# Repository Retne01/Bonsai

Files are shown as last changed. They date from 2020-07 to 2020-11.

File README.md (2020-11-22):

# Bonsai
This is a completely through hole 75% take on the TGR Alice layout.

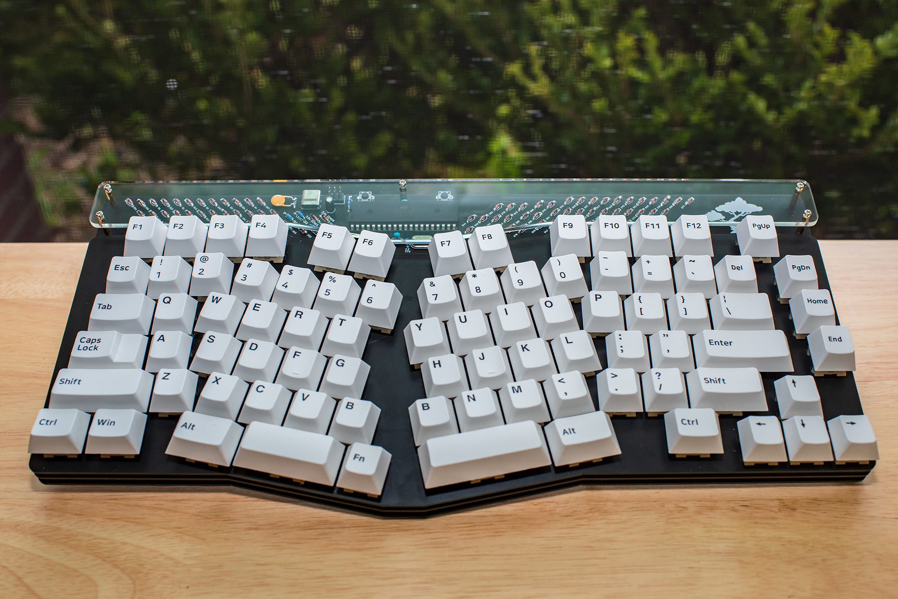
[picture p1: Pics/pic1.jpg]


If you want to put one together for yourself you can follow the guide for the FR4 sandwich style pictured above you can follow [the guide here](./Guides/FR4/)  If you would prefer to make an acrylic style case as pictured below you can follow [the guide here](./Guides/Acrylic/).

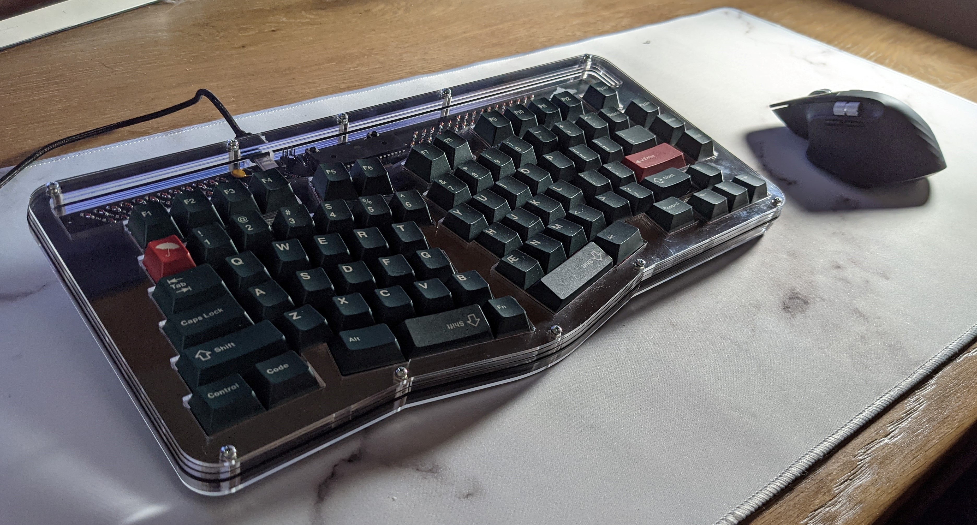
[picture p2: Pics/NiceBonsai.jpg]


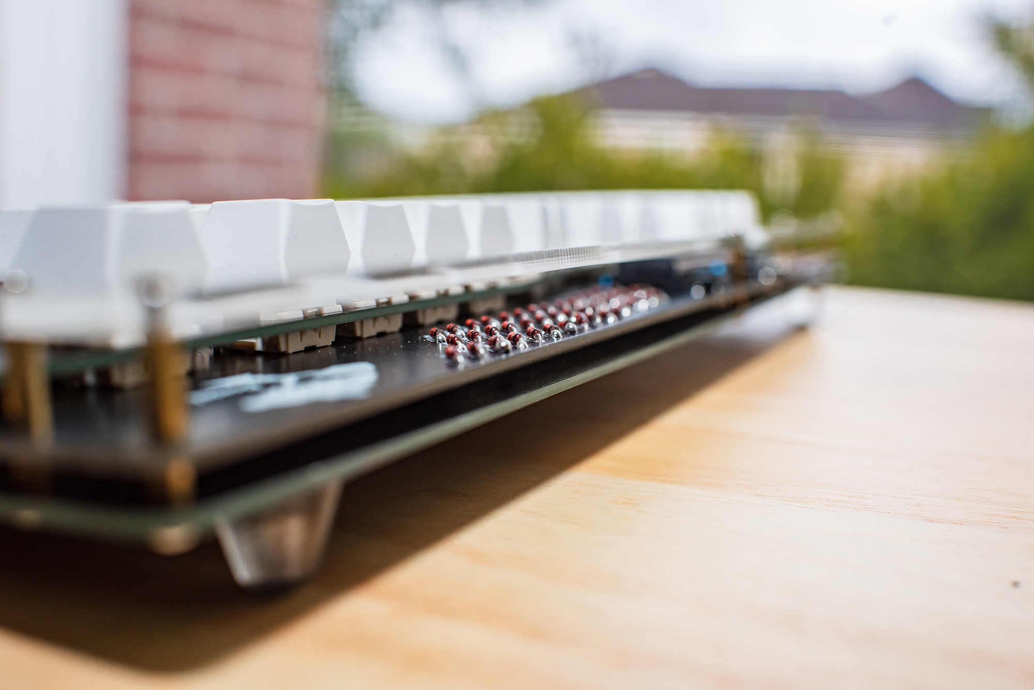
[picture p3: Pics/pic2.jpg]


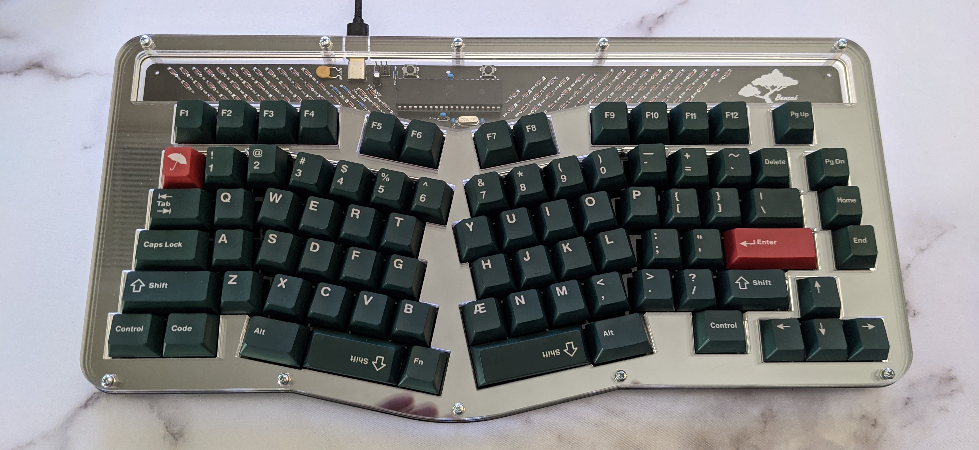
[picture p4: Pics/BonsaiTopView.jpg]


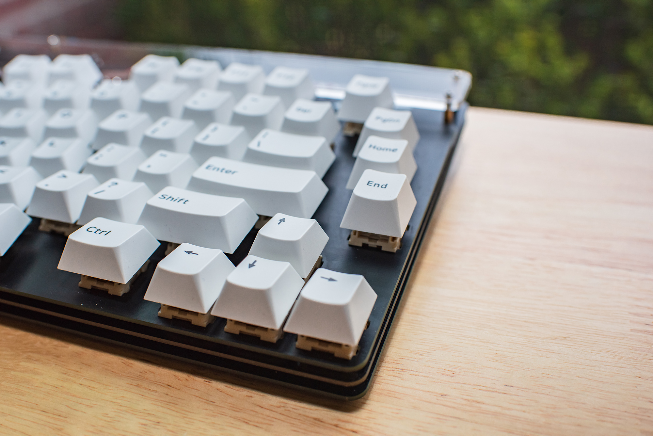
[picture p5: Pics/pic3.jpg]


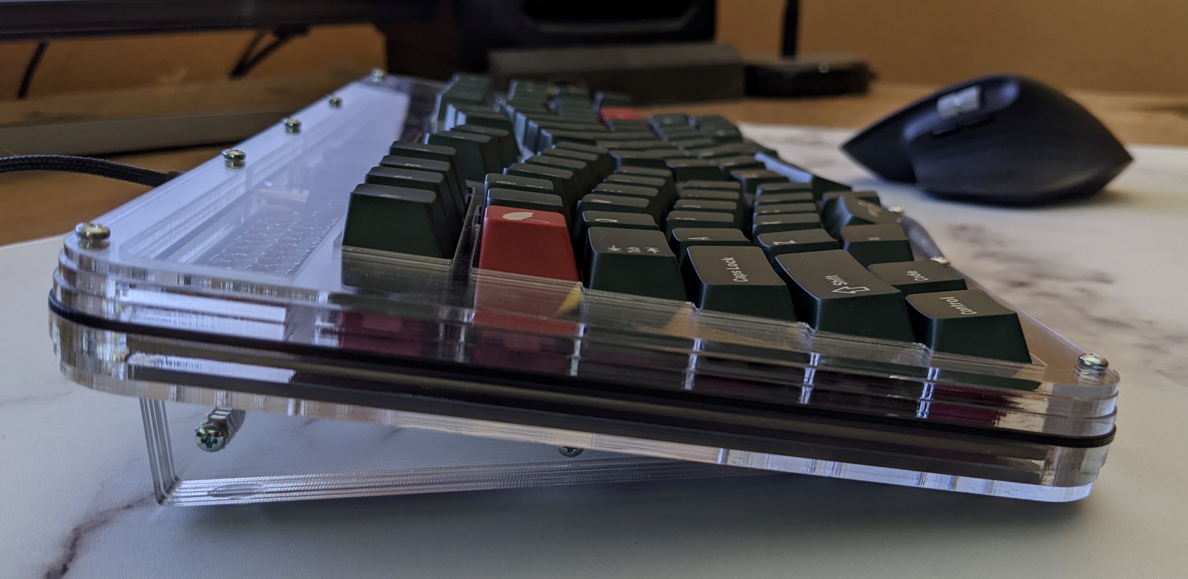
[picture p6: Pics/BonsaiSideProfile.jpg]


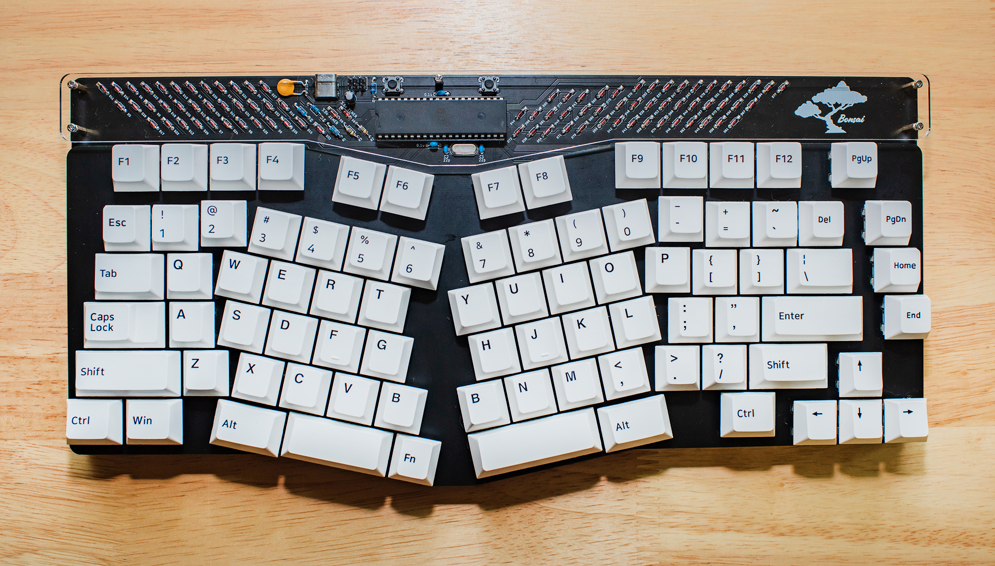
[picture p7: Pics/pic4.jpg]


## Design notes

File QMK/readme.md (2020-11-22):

# Bonsai

Bonsai

A 75% take on the Alice that can be assembled with only through hole components, including usb type-c

* Keyboard Maintainer: [Retne](https://github.com/Retne01)
* Hardware Supported: Bonsai, atmega32a
* Hardware Availability: [GitHub](https://github.com/Retne01/Bonsai)

Make example for this keyboard (after setting up your build environment):

    make bonsai:default

See the [build environment setup](https://docs.qmk.fm/#/getting_started_build_tools) and the [make instructions](https://docs.qmk.fm/#/getting_started_make_guide) for more information. Brand new to QMK? Start with our [Complete Newbs Guide](https://docs.qmk.fm/#/newbs).

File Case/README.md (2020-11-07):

# Acrylic Case for the Bonsai



This is a layered acrylic case design for the Bonsai.  The USB cutout might be a little slim so if your custom USB cable uses more than heatshrink to wrap the USB C end it probably won't fit.



If you plan to build the Bonsai with this case make sure to only order the main pcb and not the base plate or switch plate as this case will negate the need for both.



If you order this from Ponoko here are the material types and thicknesses to use:

01 - Bonsai-Top1-2mm - As the file name suggests use 2mm acrylic.

02 - Bonsai-Top2-3mm - 3mm acrylic

03 - Bonsai-Top3-3mm - 3mm acrylic

04 - Bonsai-Plate-1-5mm - 1.5mm Delrin.  This can be black or white.

05 - Bonsai-BottomOpen-4-5mm - 4.5mm acrylic

06 - Bonsai-BottomClosedwFeet-3mm - 3mm acrylic

07 - Bonsai-Bottom03mm - 3mm acrylic

You will also need [10 M2.5 14mm standoffs](https://www.harwin.com/products/R25-1001402/), [4 M2.5 11mm standoffs](https://www.harwin.com/products/R25-1001102/), [4 M2 4mm nuts](https://www.harwin.com/products/M80-2430000B/), [4 M2 6mm screws](https://www.amazon.com/gp/product/B07HGNNCLV/), and [14 M2.5 5mm screws](https://www.amazon.com/Machine-Plated-Phillips-M2-5-0-45-Threads/dp/B000NHVPPO/).

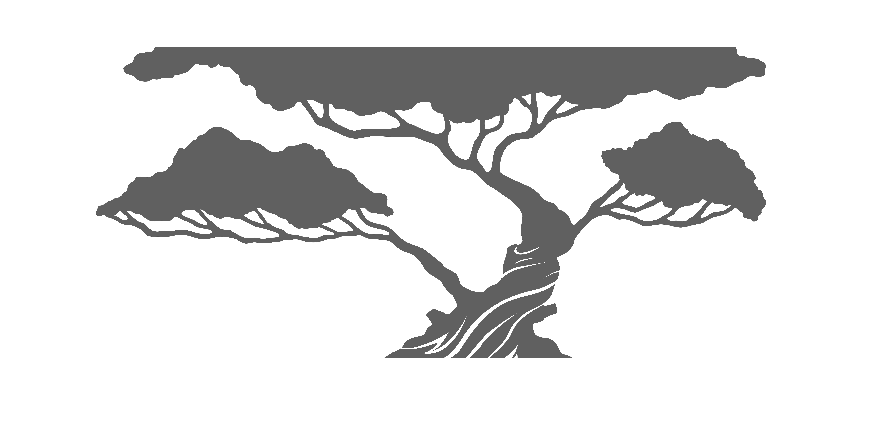
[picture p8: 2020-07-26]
Art/bonsai pcb back-01-01.png

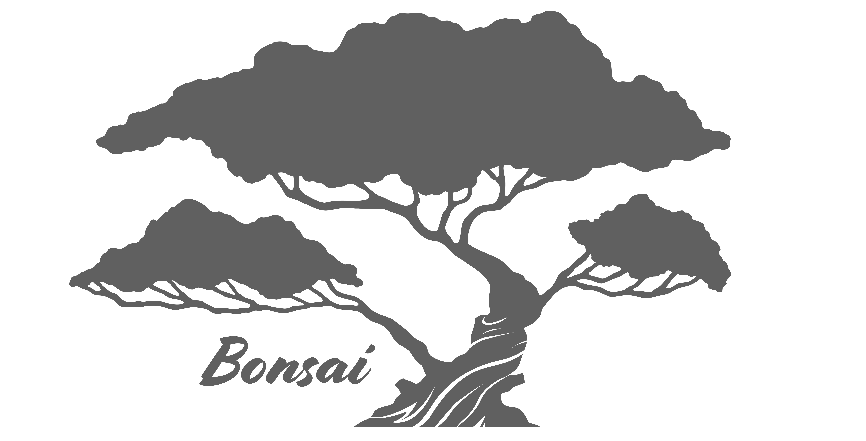
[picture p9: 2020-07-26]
Art/bonsai keyboard backplate-01-01.png

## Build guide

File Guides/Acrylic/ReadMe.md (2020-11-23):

# Acrylic Bonsai

This is a guide from start to finish of how to build an FR4 sandwich Bonsai keyboard.



1. Go to https://jlcpcb.com/ and order ONLY the "PCB Gerbers.zip" from the [Gerbers folder](https://github.com/Retne01/Bonsai/tree/master/Gerbers).  The MOQ for JLC prototypes is 5 so you will end up with 5 PCBs.

2. Order all the parts you need from the [bill of materials](https://octopart.com/bom-tool/dQECSo9X).  What vendor you choose will be up to you.  I used [Mouser](https://www.mouser.com/) and if you choose to go with them I recommend stating that you would like the parts to ship separately.  When I ordered from them I did not select this and I watched items cycle in and out of stock without them setting anything aside for my order which was very frustrating.  Another place that might be worth looking at is [LCSC](https://lcsc.com/).  I recommend trying to find a place with the majority of the items in stock if not all of them in stock as the parts are pretty darn cheap and the cost will increase exponentially if you're having to pay for shipping from multiple vendors.  I also recommend checking with your local electronic parts stores as it's always good to support local businesses.  Even if they don't stock these parts regularly they might be able to special order them for you and save you a bunch of hassle.

3. Order the acrylic case, standoffs, and screws that you will need to assemble the case.  [The files for the case can be found here](https://github.com/Retne01/Bonsai/tree/master/Case).  Pay attention to the recommended thicknesses for ordering the acrylic case from [Ponoko](https://www.ponoko.com/).  You will only need to order one of each file unless you plan to make multiple boards.  The more you order the bigger the discount.  When I ordered one case I chose to take the long wait for free shipping and the price came to roughly $127 and took roughly a month and a half to arrive.  You can also find at the bottom of that ReadMe the amount, types, and sizes of standoffs and screws.  The links to the standoffs should take you to the Harwin site and if you scroll down you can find some suggested vendors depending on where you're ordering from.  I used Mouser as the supplier of my standoffs and Amazon for the scews.  Be sure to order the [Harwin 4mm nuts](https://www.harwin.com/products/M80-2430000B/) otherwise you'll have to edit the acrylic feet to fit your chosen nut.  You'll also want to order some [bumpons](https://www.amazon.com/gp/product/B06XCGM8JT/) to go on the bottom of the feet.

4. Make sure that you have a soldering iron, some steel mesh to clean your soldering iron, some flux, some solder, and a solder sucker.  I also recommend soldering in a well ventilated area and try to have a fan pulling the solder away from the solder site as inhaling solder fumes on the regular is not good for your health.

5. Once all the parts arrive get everything together and make sure you have the correct number of parts for your build.  You should have 1x ATmega32A, 2x 75ohm resistors, 1x 1.5k resistor, 2x 5.1k resistors, 1x 10k resistor, 1x 4.7uF capacitor, 2x 0.1uF capacitors, 2x 22pF capacitors, 2x 4-pin switches, 1x 6-pin connection header, 2x 3.6v zener diodes, 1x 40-pin IC socket, 82x 1N4148 diodes, 1x 0.5amp fuse, 1x 16MHz crystal, and 1x USB-C port.

6. Solder 82x 1N4148 Diodes.  These have a specific orientation.  The black bar will be oriented upwards and go on the side with the square pad.

7. Solder the 2x 3.6v zener diodes.  These have a specific orientation.  The black bar will be oriented upwards and go on the side with the square pad.

8. Solder the 2x 75ohm, 1.5k, 2x 5.1k, and 10k resistors.  These do not hace a specific orientation.

9. Solder the USB-C port.  This will be the most dificult part and I recommend having flux on hand.  Insert the port and then solder one of the large legs to secure the port to the board.  Then heat the one leg you soldered up and press the port into the board to make sure it is flush with the board.  Apply a large amount of flux to the soldering area.  This will help you to not bridge any of the pins.  Solder the 3 legs.  Now take your iron and apply solder to the iron itself and then drag it across the pins.  Inspect to make sure all the pins are soldered and that none of them are connected to each other with solder.  If you do have two pins connected with solder, clean your iron and then heat the area with the bridged pins and pull away some of the solder.  If when you plug the board into your computer for testing you get a USB port voltage error you will know you have bridged pins and you need to inspect them again, apply flux, and try to pull away solder until none of the pins are touching but they are all soldered.

10. Solder the 2x 4-pin switches.  These have no specific orientation.

11. Solder the 0.5amp fuse.  This has no specific orientation.

12. Solder the 6-pin header.  The longer side is the bit you want sticking out of the top of your board.  I would recommend soldering 1 pin and then reheating that 1 pin and pressing the header in to make sure it sits flush with the board.

13. Solder the 16MHz crystal.  This has no specific orientation.

14. Solder the 2x 22pF capacitors.  These have no specific orientation.

15. Solder the 2x 0.1uF capacitors.  These have no specific orientation.

16. Solder the 40-pin IC socket.  This has a specific orientation.  Do not inset the MCU before soldering the IC socket.  Align the notch on the socket with the notch printed on the board.  Solder 2 pins in opposite corners.  Then reheat one pin and push down on that side and do the same with the other until the socket is flush with the board.

17. Insert the ATmega32A into the IC socket.  Be sure to line up the notch on the MCU with the notch on the socket.  You may need to gently bend the pin legs to get them aligned with the socket.  I recommend sticking one sideof the MCU's legs into the socket and gently bending the opposite legs to align with the socket and then gently pressing the MCU into the socket.  Then solder the rest of the pins.

18. It's time to flash the bootloader.  Get your AVR programmer out and download [the bootloader](https://github.com/Retne01/Bonsai/tree/master/Bootloader).  Install [WinAVR](http://winavr.sourceforge.net/) and [set up your QMK build environment](https://beta.docs.qmk.fm/tutorial/newbs_getting_started).  If you are not using a Sparkfun Pocket AVR Programmer you will need to edit the makefile.inc to use the programmer of your choice.  Be sure to only edit the makefile.inc and not the makefile itself.  Once done connect your programmer to the 6-pin header and open MinGW64.  Navigate to the bootloader directory and run these two commands

	```make flash```
	```make fuse```

The USB bootloader should now be flashed.  You can now remove your AVR Programmer.

19. Now we'll flash your desired QMK firmware layout to the MCU.  Connect the board to your computer with a USB cable and hold down the boot switch, tap the reset switch, and release the boot switch.  You can also hold down the boot switch while inserting the USB cable into the board if you prefer.  This will put the board into bootloader mode.  Make sure you've downloaded the [bonsai QMK source](https://github.com/Retne01/Bonsai/tree/master/QMK) and put it in $/qmk_firmware/keyboards/bonsai/.  Open MinGW64 and navigate to $/qmk_firmware/.  Then run one of the following commands depending on your preferred layout:

	```make bonsai:default:flash```
	
	or

	```make bonsai:split_bksp:flash```

You should see something similar to this:

![](./pics/qmkflash.jpg)

Your keyboard should now be flashed and you can now unplug the USB cable.  I have not added this board to QMK with a pull request because I expect very few people to be interested in the board at all.  If you want to edit the layout you can look at the source I've provided and edit it to your liking.  You can find a list of [qmk key codes here](https://beta.docs.qmk.fm/using-qmk/simple-keycodes/keycodes).

20.  Plug your board back in, grab a pair of tweesers and test to make sure all of the switch holes are working in whatever keyboard tester you prefer.

21. Now grab your acrylic parts, standoffs, and screws.  You should have 6 acrylic layers and one POM/Delrin layer.  For your standoffs and screws you should have 10x M2.5 14mm standoffs, 4x M2.5 11mm standoffs, 4x M2 4mm nuts, 4x M2 6mm screws, and 14x M2.5 5mm screws.

22. Lube, assemble, and attach your stabalizers to the board.  You will need 4 or 5 depending on if you are splitting the backspace or not.

23. Line up the POM plate with the board and insert all of your switches.  If you have trouble getting them to insert fully into the plate you can insert almost all the switches into the plate and then line it up with the board to insert the last few.

24. Solder your switches into the board.  I recommend soldering one leg on a handful of switches around the board and then reflowing the joints while pressing the switches into the board to ensure you get them nice and flush with the PCB.  Once you've got everything sitting flush go ahead and solder the rest of your switch legs.

25. Now take the 12x acrylic triangles and separate them into 2 piles with 2 of each kind going into the piles.  Then take from one pile one of the triangles with the hexaganal cutouts but no notch and line it up with 2 of the triangles from the pile that have the hexaganal cutouts AND the notch.  Then align those with one of the triangles that only has screw holes from the same pile.  Slide 2x 11mm standoffs into the hexaganal holes and screw them into the triangle with screw holes.  Now slide 2x 4mm nuts into the notches, align the last triangle with hexaganal cutouts, and finally align the last triangle from the pile with screw holes and screw them into the standoffs.  Now duplicate the process with the other pile and you will have your case feet.

26. Use the 4x M2 screws to screw the feet into the base of the case (layer 7) by aligning the holes in the middle of the base with the nuts in the feet.

27. Now take layer 6 of the case and line it up with the base of the case.  Slot in all 10x M2.5 14mm standoffs and screw them into the base lightly.

28. Stack layer 5 on top of layer 6 and then slide the assembled board in.

29. Stack layer 3, 2, and 1 on top of the plate and screw the top into the standoffs.

Congratulations, you now have an Acrylic Bonsai to type away with.

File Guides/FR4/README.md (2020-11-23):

# FR4 Sandwich Bonsai

This is a guide from start to finish of how to build an FR4 sandwich Bonsai keyboard.



1. Go to https://jlcpcb.com/ and order all 3 gerbers from the [Gerbers folder](https://github.com/Retne01/Bonsai/tree/master/Gerbers).  There are 3 of them.  The base plate, the pcb, and the switch plate.  The MOQ for JLC prototypes is 5 so you will end up with 5 of each.  If they ask you about missing copper in the switch plate or base plate just tell them that you don't need copper in those but definitely make sure to go with a pcb color.  With default pcb coloring they may look worse than if you opt for something like Black.  They may also ask you about the drill holes being too close together on the switch plate.  Tell them that you will accept damages and they will make it.  I had all 5 of my FR4 switch plates come out just fine and I had to do this.

2. Order all the parts you need from the [bill of materials](https://octopart.com/bom-tool/dQECSo9X).  What vendor you choose will be up to you.  I used [Mouser](https://www.mouser.com/) and if you choose to go with them I recommend stating that you would like the parts to ship separately.  When I ordered from them I did not select this and I watched items cycle in and out of stock without them setting anything aside for my order which was very frustrating.  Another place that might be worth looking at is [LCSC](https://lcsc.com/).  I recommend trying to find a place with the majority of the items in stock if not all of them in stock as the parts are pretty darn cheap and the cost will increase exponentially if you're having to pay for shipping from multiple vendors.  I also recommend checking with your local electronic parts stores as it's always good to support local businesses.  Even if they don't stock these parts regularly they might be able to special order them for you and save you a bunch of hassle.

3. Order [some standoffs](https://www.amazon.com/gp/product/B07B9X1KY6/) and [bumpons](https://www.amazon.com/gp/product/B06XCGM8JT/) of [different heights](https://www.amazon.com/gp/product/B07KGKZFQN/).  The stuff I'm linking to here is what I ordered for my project but there may be better stuff out there.  The standoffs will determine the height of the PCB from the Base Plate and the bumpons will determine the angle of the board.  With the two bumpons I linked if the small ones are used at the front of the keyboard and the large ones at the back you will get roughly a 5-6 degree typing angle.  I haven't measured it but it lined up pretty close with my tofu65.

4. Order the acrylic window for your keyboard.  You can use the SVG [found here](https://github.com/Retne01/Bonsai/tree/master/Acrylic%20Top) to order them cut at [Ponoko](https://www.ponoko.com/) or whichever laser cutting service you prefer.  Just be sure to order clear acrylic to show off your soldering work!

5. Make sure that you have a soldering iron, some steel mesh to clean your soldering iron, some flux, some solder, and a solder sucker.  I also recommend soldering in a well ventilated area and try to have a fan pulling the solder fumes away from the solder site as inhaling solder fumes on the regular is not good for your health.

6. Once all the parts arrive get everything together and make sure you have the correct number of parts for your build.  You should have 1x ATmega32A, 2x 75ohm resistors, 1x 1.5k resistor, 2x 5.1k resistors, 1x 10k resistor, 1x 4.7uF capacitor, 2x 0.1uF capacitors, 2x 22pF capacitors, 2x 4-pin switches, 1x 6-pin connection header, 2x 3.6v zener diodes, 1x 40-pin IC socket, 82x 1N4148 diodes, 1x 0.5amp fuse, 1x 16MHz crystal, and 1x USB-C port.

7. Solder 82x 1N4148 Diodes.  These have a specific orientation.  The black bar will be oriented upwards and go on the side with the square pad.

8. Solder the 2x 3.6v zener diodes.  These have a specific orientation.  The black bar will be oriented upwards and go on the side with the square pad.

9. Solder the 2x 75ohm, 1.5k, 2x 5.1k, and 10k resistors.  These do not hace a specific orientation.

10. Solder the USB-C port.  This will be the most dificult part and I recommend having flux on hand.  Insert the port and then solder one of the large legs to secure the port to the board.  Then heat the one leg you soldered up and press the port into the board to make sure it is flush with the board.  Apply a large amount of flux to the soldering area.  This will help you to not bridge any of the pins.  Solder the 3 legs.  Now take your iron and apply solder to the iron itself and then drag it across the pins.  Inspect to make sure all the pins are soldered and that none of them are connected to each other with solder.  If you do have two pins connected with solder, clean your iron and then heat the area with the bridged pins and pull away some of the solder.  If when you plug the board into your computer for testing you get a USB port voltage error you will know you have bridged pins and you need to inspect them again, apply flux, and try to pull away solder until none of the pins are touching but they are all soldered.

11. Solder the 2x 4-pin switches.  These have no specific orientation.

12. Solder the 0.5amp fuse.  This has no specific orientation.

13. Solder the 6-pin header.  The longer side is the bit you want sticking out of the top of your board.  I would recommend soldering 1 pin and then reheating that 1 pin and pressing the header in to make sure it sits flush with the board.

14. Solder the 16MHz crystal.  This has no specific orientation.

15. Solder the 2x 22pF capacitors.  These have no specific orientation.

16. Solder the 2x 0.1uF capacitors.  These have no specific orientation.

17. Solder the 40-pin IC socket.  This has a specific orientation.  Do not inset the MCU before soldering the IC socket.  Align the notch on the socket with the notch printed on the board.  Solder 2 pins in opposite corners.  Then reheat one pin and push down on that side and do the same with the other until the socket is flush with the board.  Then solder the rest of the pins.

18. Insert the ATmega32A into the IC socket.  Be sure to line up the notch on the MCU with the notch on the socket.  You may need to gently bend the pin legs to get them aligned with the socket.  I recommend sticking one sideof the MCU's legs into the socket and gently bending the opposite legs to align with the socket and then gently pressing the MCU into the socket.

19. It's time to flash the bootloader.  Get your AVR programmer out and download [the bootloader](https://github.com/Retne01/Bonsai/tree/master/Bootloader).  Install [WinAVR](http://winavr.sourceforge.net/) and [set up your QMK build environment](https://beta.docs.qmk.fm/tutorial/newbs_getting_started).  If you are not using a Sparkfun Pocket AVR Programmer you will need to edit the makefile.inc to use the programmer of your choice.  Be sure to only edit the makefile.inc and not the makefile itself.  Once done connect your programmer to the 6-pin header and open MinGW64.  Navigate to the bootloader directory and run these two commands

	```make flash```
	```make fuse```

The USB bootloader should now be flashed.  You can now remove your AVR Programmer.

20. Now we'll flash your desired QMK firmware layout to the MCU.  I've found that QMK Toolbox does not like to work with the board until I've already flashed QMK to it so for these next steps you'll need to have the qmk build environment set up.  Connect the board to your computer with a USB cable and hold down the boot switch, tap the reset switch, and release the boot switch.  You can also hold down the boot switch while inserting the USB cable into the board if you prefer.  This will put the board into bootloader mode.  Make sure you've downloaded the [bonsai QMK source](https://github.com/Retne01/Bonsai/tree/master/QMK) and put it in $/qmk_firmware/keyboards/bonsai/.  Open MinGW64 and navigate to $/qmk_firmware/.  Then run one of the following commands depending on your preferred layout:

	```make bonsai:default:flash```

	or
	
	```make bonsai:split_bksp:flash```

You should see something similar to this:

![](./pics/qmkflash.jpg)

Your keyboard should now be flashed and you can now unplug the USB cable.  I have not added this board to QMK with a pull request because I expect very few people to be interested in the board at all.  If you want to edit the layout you can look at the source I've provided and edit it to your liking.  You can find a list of [qmk key codes here](https://beta.docs.qmk.fm/using-qmk/simple-keycodes/keycodes).

21. Plug your board back in, grab a pair of tweesers and test to make sure all of the switch holes are working in whatever keyboard tested you prefer.

22. Now you will need to gather your standoffs, screws, MX switches of your choice, the switch plate, and the base plate.

23. Choose the height of standoff you want for connected the base plate to the board and be sure to use female to female standoffs.  Screw the standoffs that connect below the switch plate into the bottom of the board.  Then screw in the 5 standoffs that go into the top of the board.  For the top of the board you will use the longer male to female standoffs and female to female standoffs of the same size as the ones you previously selected on the bottom of the board.

24. Lube, assemble, and attach your stabalizers to the board.

25. Insert the MX switches into the switch plate and into the board.

26. Solder one leg of a handful of switches across the board to act as anchor points.  Then reflow each switch and be sure to push it all the way into the board until it is flush with the board.  Then solder the rest of the switch legs.

27. Screw in the base plate to the standoffs on the back of the board and screw the acrylic window into the standoffs at the top of the board.

Congratulations, you now have an FR4 Bonsai of your very own.

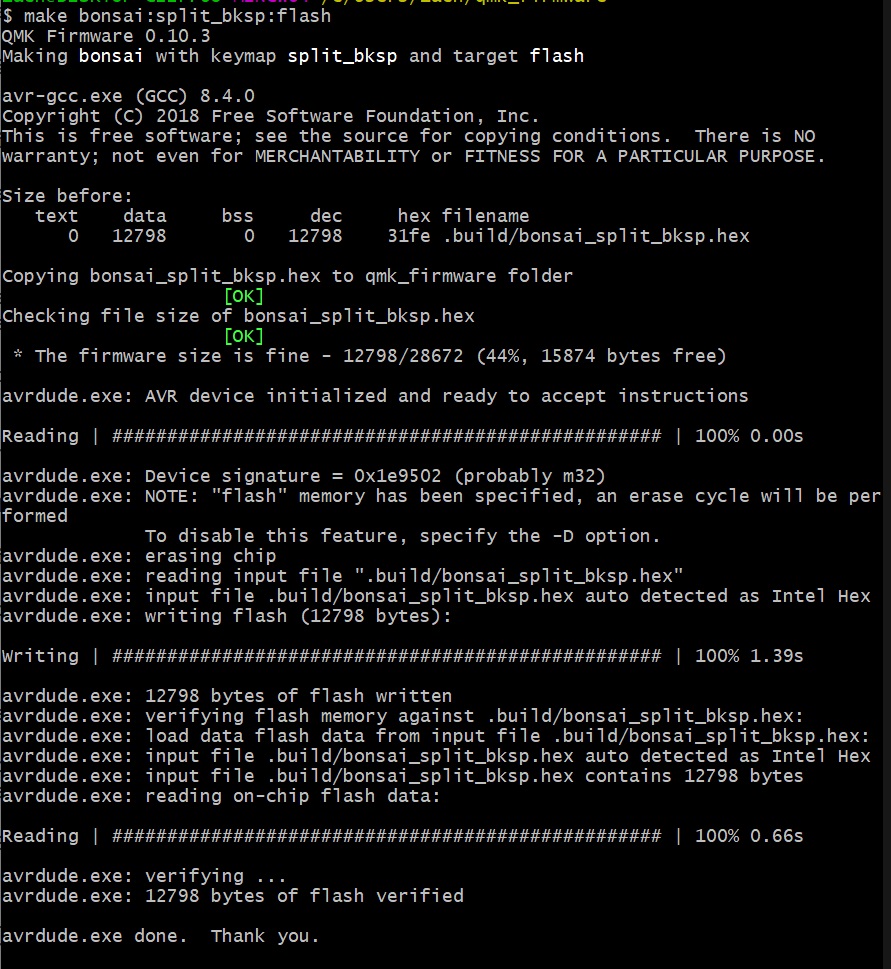
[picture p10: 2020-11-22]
Guides/FR4/pics/qmkflash.jpg

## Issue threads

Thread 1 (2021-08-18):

Gerber Files

killrmodz, 2021-08-18:
Currently, JLPCB is unable to process the main gerber files for the pcb.  Just wanted to bring this to your attention as I wanted to order some PCB's.

Thanks!

Retne01, 2021-08-18:
What do they say is the issue?  Or is it their automated system not working
with it?

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

killrmodz, 2021-08-18:
It seems like their automated system maybe when uploading gerber files with the main pcb?  The plates will upload.  Man pcb says it completes but the gerber viewer doesn’t show up.  Led me to contacting you on github.

Ismael Justiniano
Owner/Founder of killRMODZ
Facebook.com/killrmoddingz

On Aug 18, 2021, at 7:32 AM, Retne01 ***@***.***> wrote:

What do they say is the issue? Or is it their automated system not working
with it?

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

—
You are receiving this because you authored the thread.
Reply to this email directly, view it on GitHub<https://na01.safelinks.protection.outlook.com/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>, or unsubscribe<https://na01.safelinks.protection.outlook.com/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>.
Triage notifications on the go with GitHub Mobile for iOS<https://na01.safelinks.protection.outlook.com/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> or Android<https://na01.safelinks.protection.outlook.com/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>.

Retne01, 2021-08-18:
Sometimes JLC's Gerber viewer doesn't work properly but they can still make
the pcb just fine. I'll take a look tonight and see if I have the same
issue and get back to you.

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

killrmodz, 2021-08-18:
You rock, thanks!

Ismael Justiniano
Owner/Founder of killRMODZ
Facebook.com/killrmoddingz

On Aug 18, 2021, at 7:41 AM, Retne01 ***@***.***> wrote:

Sometimes JLC's Gerber viewer doesn't work properly but they can still make
the pcb just fine. I'll take a look tonight and see if I have the same
issue and get back to you.

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

—
You are receiving this because you authored the thread.
Reply to this email directly, view it on GitHub<https://na01.safelinks.protection.outlook.com/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>, or unsubscribe<https://na01.safelinks.protection.outlook.com/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>.
Triage notifications on the go with GitHub Mobile for iOS<https://na01.safelinks.protection.outlook.com/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> or Android<https://na01.safelinks.protection.outlook.com/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>.

Retne01, 2021-08-18:
It does indeed appear to just be typical JLC bugginess of their gerber
preview.  You should still be able to proceed with the order.  I was able
to upload the gerbers fine but you will have to manually enter the pcb size
which is 349mm x 166mm.  Once you purchase it the engineers at JLC will
ingest the gerbers.  They will most likely ask you "Will you accept broken
PCBs?" on the plate gerbers since the drill points are closer than their
safety spec.  Don't worry though they will still come out fine.  Mine came
out clean and CFT has used JLC for FR4 plates with similar
positive results.  They'll also likely ask if the base or the plate needs a
ground pour or not.  It does not and it should make the parts cheaper to
get them without.

If the engineers get back to you and tell you there is an issue with the
PCB gerber let me know and I'll regenerate the gerbers and replace them on
github.  Feel free to hit me up if you have any questions when building and
flashing and I'll do my best to help.

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

killrmodz, 2021-08-19:
You’re awesome!!  Im a professional modder that makes custom water cooled pc.  Ever need any custom work, just hit me up!

Ill let you know how it goes!

Ismael Justiniano
Owner/Founder of killRMODZ
Facebook.com/killrmoddingz

On Aug 18, 2021, at 7:50 PM, Retne01 ***@***.***> wrote:

It does indeed appear to just be typical JLC bugginess of their gerber
preview. You should still be able to proceed with the order. I was able
to upload the gerbers fine but you will have to manually enter the pcb size
which is 349mm x 166mm. Once you purchase it the engineers at JLC will
ingest the gerbers. They will most likely ask you "Will you accept broken
PCBs?" on the plate gerbers since the drill points are closer than their
safety spec. Don't worry though they will still come out fine. Mine came
out clean and CFT has used JLC for FR4 plates with similar
positive results. They'll also likely ask if the base or the plate needs a
ground pour or not. It does not and it should make the parts cheaper to
get them without.

If the engineers get back to you and tell you there is an issue with the
PCB gerber let me know and I'll regenerate the gerbers and replace them on
github. Feel free to hit me up if you have any questions when building and
flashing and I'll do my best to help.

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

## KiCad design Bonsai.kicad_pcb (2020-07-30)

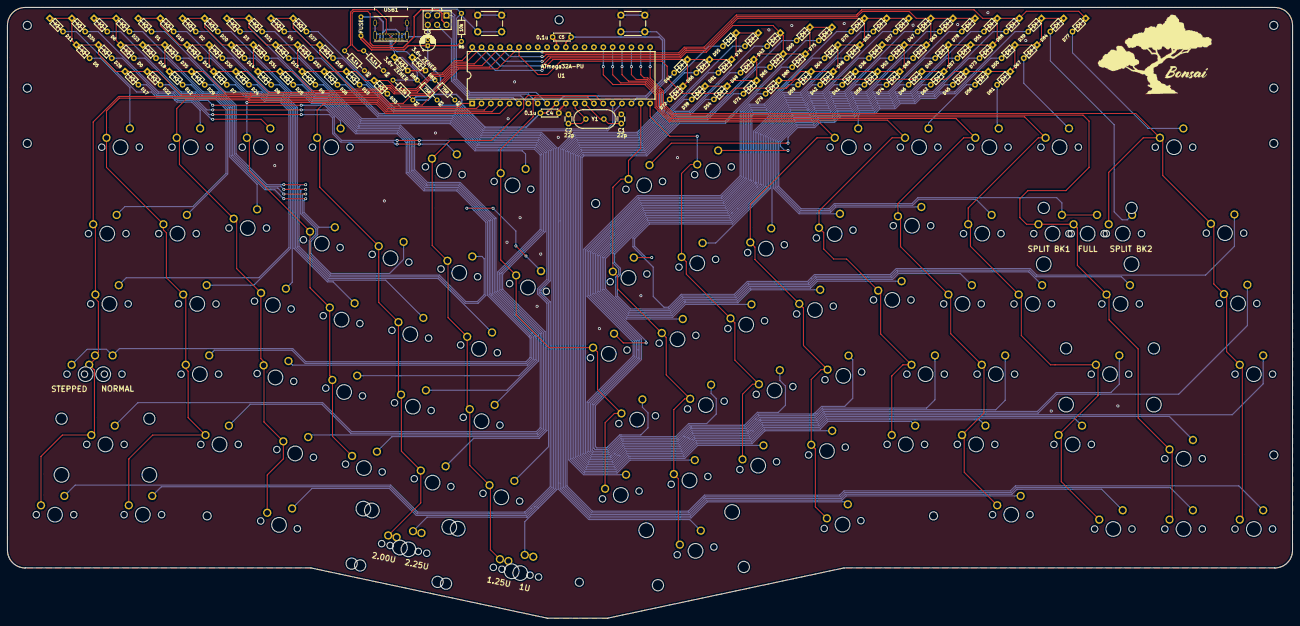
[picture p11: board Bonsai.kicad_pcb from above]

Board: 2 copper layers, 348.5 x 165.6 mm, 203 parts (0 on the bottom side), 120 nets.

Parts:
BOOT1: BOOT; SW_PUSH_6mm
C1, C2: 22p; C_Disc_D3.0mm_W1.6mm_P2.50mm
C3: 4.7u; CP_Radial_D4.0mm_P1.50mm
C4, C5: 0.1u; C_Disc_D4.3mm_W1.9mm_P5.00mm
D0, D1, D2, D3, D4, D5, D6, D7, D8, D9, D10, D11, D12, D13, D14, D15, D16, D17, D18, D19, D20, D21, D22, D23, D24, D25, D26, D27, D28, D29, D30, D31, D32, D33, D34, D35, D36, D37, D38, D39, D40, D41, D42, D43, D44, D45, D46, D47, D48, D49, D50, D51, D52, D53, D54, D55, D56, D57, D58, D59, D60, D61, D62, D63, D64, D65, D66, D67, D68, D69, D70, D71, D72, D73, D74, D75, D76, D77, D78, D79, D80, D81, D84: D; D_DO-35_SOD27_P5.08mm_Horizontal
D82, D83: 3.6v; D_DO-35_SOD27_P5.08mm_Horizontal
F1: 500mA; polyfuse_5.1mm
G01: LOGO; Bonsai Front Badge 6k x6k
H1, H2, H3, H4, H5, H6, H7, H8, H9, H10, H11, H12: MountingHole; MountingHole_2.2mm_M2
J1: AVR-ISP-6; AVR_ICSP_3x2
R1: 1.5k; R_Axial_DIN0204_L3.6mm_D1.6mm_P7.62mm_Horizontal
R2, R3: 75R; R_Axial_DIN0204_L3.6mm_D1.6mm_P7.62mm_Horizontal
R4, R5: 5.1k; R_Axial_DIN0204_L3.6mm_D1.6mm_P7.62mm_Horizontal
R6: 10k; R_Axial_DIN0204_L3.6mm_D1.6mm_P7.62mm_Horizontal
RESET1: RESET; SW_PUSH_6mm
SW_1, SW_2, SW_3, SW_4, SW_5, SW_6, SW_7, SW_8, SW_9, SW_10: SW_Push; MXOnly-1U-NoLED
SW_A1: SW_Push; MXOnly-1U-NoLED
SW_APST1: SW_Push; MXOnly-1U-NoLED
SW_BKSP1: SW_Push; MXOnly-2U-NoLED
SW_BKSP11, SW_BKSP12: SW_Push; MXOnly-1U-NoLED
SW_B_LEFT1: SW_Push; MXOnly-1U-NoLED
SW_B_RIGHT1: SW_Push; MXOnly-1U-NoLED
SW_C1: SW_Push; MXOnly-1U-NoLED
SW_COMMA1: SW_Push; MXOnly-1U-NoLED
SW_CPLK1: SW_Push; MXOnly-1.75U-NoLED
SW_CPLKSTPD1: SW_Push; MXOnly-1.25U-NoLED
SW_D1: SW_Push; MXOnly-1U-NoLED
SW_DASH1: SW_Push; MXOnly-1U-NoLED
SW_DOWN1: SW_Push; MXOnly-1U-NoLED
SW_E1: SW_Push; MXOnly-1U-NoLED
SW_ENT1: SW_Push; MXOnly-2.25U-NoLED
SW_ESC1: SW_Push; MXOnly-1U-NoLED
SW_F1, SW_F2, SW_F3, SW_F4, SW_F5, SW_F6, SW_F7, SW_F8, SW_F9, SW_F10, SW_F11, SW_F12, SW_F13: SW_Push; MXOnly-1U-NoLED
SW_FN1: SW_Push; MXOnly-1U-NoLED
SW_FN2: SW_Push; MXOnly-1.25U-NoLED
SW_G1: SW_Push; MXOnly-1U-NoLED
SW_H1: SW_Push; MXOnly-1U-NoLED
SW_I1: SW_Push; MXOnly-1U-NoLED
SW_J1: SW_Push; MXOnly-1U-NoLED
SW_K1: SW_Push; MXOnly-1U-NoLED
SW_L1: SW_Push; MXOnly-1U-NoLED
SW_LALT1: SW_Push; MXOnly-1.5U-NoLED
SW_LCTRL1: SW_Push; MXOnly-1.25U-NoLED
SW_LEFT1: SW_Push; MXOnly-1U-NoLED
SW_LSHFT1: SW_Push; MXOnly-2.25U-NoLED
SW_LSPC1: SW_Push; MXOnly-2.25U-ReversedStabilizers-NoLED
SW_LSPC2: SW_Push; MXOnly-2U-ReversedStabilizers-NoLED
SW_M1, SW_M2, SW_M3, SW_M4, SW_M5: SW_Push; MXOnly-1U-NoLED
SW_N1: SW_Push; MXOnly-1U-NoLED
SW_O1: SW_Push; MXOnly-1U-NoLED
SW_P1: SW_Push; MXOnly-1U-NoLED
SW_PLUS1: SW_Push; MXOnly-1U-NoLED
SW_PRD1: SW_Push; MXOnly-1U-NoLED
SW_Q1: SW_Push; MXOnly-1U-NoLED
SW_R1: SW_Push; MXOnly-1U-NoLED
SW_RALT1: SW_Push; MXOnly-1.5U-NoLED
SW_RCTRL1: SW_Push; MXOnly-1.25U-NoLED
SW_RGHT1: SW_Push; MXOnly-1U-NoLED
SW_RSHFT1: SW_Push; MXOnly-1.75U-NoLED
SW_RSPC1: SW_Push; MXOnly-2.75U-ReversedStabilizers-NoLED
SW_S1: SW_Push; MXOnly-1U-NoLED
SW_SCLN1: SW_Push; MXOnly-1U-NoLED
SW_SLSH1: SW_Push; MXOnly-1U-NoLED
SW_T1: SW_Push; MXOnly-1U-NoLED
SW_TAB1: SW_Push; MXOnly-1.5U-NoLED
SW_U1: SW_Push; MXOnly-1U-NoLED
SW_UP1: SW_Push; MXOnly-1U-NoLED
SW_V1: SW_Push; MXOnly-1U-NoLED
SW_W1: SW_Push; MXOnly-1U-NoLED
SW_WIN1: SW_Push; MXOnly-1.25U-NoLED
SW_X1: SW_Push; MXOnly-1U-NoLED
SW_Y1: SW_Push; MXOnly-1U-NoLED
SW_Z1: SW_Push; MXOnly-1U-NoLED
SW_[1: SW_Push; MXOnly-1U-NoLED
SW_]1: SW_Push; MXOnly-1U-NoLED
SW_|1: SW_Push; MXOnly-1.5U-NoLED
U1: ATmega32A-PU; DIP-40_W15.24mm
USB1: USB_C_Receptacle_USB2.0; USB_C_GCT_USB4085
Y1: Crystal; Crystal_HC49-4H_Vertical

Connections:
+5V: C3.1, C4.1, C5.1, F1.1, J1.2, R1.1, R6.1, U1.10, U1.30
D+: R2.1, U1.16
D-: R3.1, U1.17
GND: BOOT1.1, C1.2, C2.2, C3.2, C4.2, C5.2, D82.2, D83.2, J1.6, R4.1, R5.1, RESET1.1, U1.11, U1.31, USB1.A1, USB1.A12, USB1.B1, USB1.B12, USB1.S1
MISO: J1.1, U1.7
MOSI: J1.4, U1.6
unnamed: C1.1, U1.13, Y1.1
unnamed: C2.1, U1.12, Y1.2
unnamed: D0.2, SW_ESC1.2
unnamed: D1.2, SW_TAB1.2
unnamed: D2.2, SW_CPLK1.2, SW_CPLKSTPD1.1
unnamed: D3.2, SW_LSHFT1.2
unnamed: D4.2, SW_LCTRL1.2
unnamed: D5.2, SW_F1.2
unnamed: D6.2, SW_1.2
unnamed: D7.2, SW_Q1.2
unnamed: D8.2, SW_A1.2
unnamed: D9.2, SW_Z1.2
unnamed: D10.2, SW_WIN1.2
unnamed: D11.2, SW_F2.2
unnamed: D12.2, SW_2.2
unnamed: D13.2, SW_W1.2
unnamed: D14.2, SW_S1.2
unnamed: D15.2, SW_X1.2
unnamed: D16.2, SW_LALT1.2
unnamed: D17.2, SW_F3.2
unnamed: D18.2, SW_3.2
unnamed: D19.2, SW_E1.2
unnamed: D20.2, SW_D1.2
unnamed: D21.2, SW_C1.2
unnamed: D22.2, SW_F4.2
unnamed: D23.2, SW_4.2
unnamed: D24.2, SW_R1.2
unnamed: D25.2, SW_F13.2
unnamed: D26.2, SW_V1.2
unnamed: D27.2, SW_LSPC1.2, SW_LSPC2.2
unnamed: D28.2, SW_F5.2
unnamed: D29.2, SW_5.2
unnamed: D30.2, SW_T1.2
unnamed: D31.2, SW_G1.2
unnamed: D32.2, SW_B_LEFT1.2
unnamed: D33.2, SW_FN1.2, SW_FN2.2
unnamed: D34.2, SW_F6.2
unnamed: D35.2, SW_6.2
unnamed: D36.2, SW_Y1.2
unnamed: D37.2, SW_H1.2
unnamed: D38.2, SW_B_RIGHT1.2
unnamed: D39.2, SW_F7.2
unnamed: D40.2, SW_7.2
unnamed: D41.2, SW_U1.2
unnamed: D42.2, SW_J1.2
unnamed: D43.2, SW_N1.2
unnamed: D44.2, SW_RSPC1.2
unnamed: D45.2, SW_F8.2
unnamed: D46.2, SW_8.2
unnamed: D47.2, SW_I1.2
unnamed: D48.2, SW_K1.2
unnamed: D49.2, SW_M5.2
unnamed: D50.2, SW_F9.2
unnamed: D51.2, SW_9.2
unnamed: D52.2, SW_O1.2
unnamed: D53.2, SW_L1.2
unnamed: D54.2, SW_COMMA1.2
unnamed: D55.2, SW_RALT1.2
unnamed: D56.2, SW_F10.2
unnamed: D57.2, SW_10.2
unnamed: D58.2, SW_P1.2
unnamed: D59.2, SW_SCLN1.2
unnamed: D60.2, SW_PRD1.2
unnamed: D61.2, SW_F11.2
unnamed: D62.2, SW_DASH1.2
unnamed: D63.2, SW_[1.2
unnamed: D64.2, SW_APST1.2
unnamed: D65.2, SW_SLSH1.2
unnamed: D66.2, SW_RCTRL1.2
unnamed: D67.2, SW_F12.2
unnamed: D68.2, SW_PLUS1.2
unnamed: D69.2, SW_]1.2
unnamed: D70.2, SW_ENT1.2
unnamed: D71.2, SW_RSHFT1.2
unnamed: D72.2, SW_LEFT1.2
unnamed: D73.2, SW_BKSP1.2, SW_BKSP11.2
unnamed: D74.2, SW_|1.2
unnamed: D75.2, SW_UP1.2
unnamed: D76.2, SW_DOWN1.2
unnamed: D77.2, SW_M1.2
unnamed: D78.2, SW_M2.2
unnamed: D79.2, SW_M3.2
unnamed: D80.2, SW_M4.2
unnamed: D81.2, SW_RGHT1.2
unnamed: D82.1, R2.2, USB1.A6, USB1.B6
unnamed: D83.1, R1.2, R3.2, USB1.A7, USB1.B7
unnamed: D84.2, SW_BKSP12.2
unnamed: R4.2, USB1.A5
unnamed: R5.2, USB1.B5
SCK: J1.3, U1.8
VCC: F1.2, USB1.A4, USB1.A9, USB1.B4, USB1.B9
boot: BOOT1.2, U1.18
col0: SW_CPLK1.1, SW_CPLKSTPD1.2, SW_ESC1.1, SW_LCTRL1.1, SW_LSHFT1.1, SW_TAB1.1, U1.1
col1: SW_1.1, SW_A1.1, SW_F1.1, SW_Q1.1, SW_WIN1.1, SW_Z1.1, U1.2
col2: SW_2.1, SW_F2.1, SW_LALT1.1, SW_S1.1, SW_W1.1, SW_X1.1, U1.3
col3: SW_3.1, SW_C1.1, SW_D1.1, SW_E1.1, SW_F3.1, U1.4
col4: SW_4.1, SW_F4.1, SW_F13.1, SW_LSPC1.1, SW_LSPC2.1, SW_R1.1, SW_V1.1, U1.5
col5: SW_5.1, SW_B_LEFT1.1, SW_F5.1, SW_FN1.1, SW_FN2.1, SW_G1.1, SW_T1.1, U1.15
col6: SW_6.1, SW_B_RIGHT1.1, SW_F6.1, SW_H1.1, SW_Y1.1, U1.14
col7: SW_7.1, SW_F7.1, SW_J1.1, SW_N1.1, SW_RSPC1.1, SW_U1.1, U1.19
col8: SW_8.1, SW_F8.1, SW_I1.1, SW_K1.1, SW_M5.1, U1.20
col9: SW_9.1, SW_COMMA1.1, SW_F9.1, SW_L1.1, SW_O1.1, SW_RALT1.1, U1.26
col10: SW_10.1, SW_F10.1, SW_P1.1, SW_PRD1.1, SW_SCLN1.1, U1.25
col11: SW_APST1.1, SW_DASH1.1, SW_F11.1, SW_RCTRL1.1, SW_SLSH1.1, SW_[1.1, U1.24
col12: SW_ENT1.1, SW_F12.1, SW_LEFT1.1, SW_PLUS1.1, SW_RSHFT1.1, SW_]1.1, U1.23
col13: SW_BKSP1.1, SW_BKSP11.1, SW_DOWN1.1, SW_UP1.1, SW_|1.1, U1.22
col14: SW_BKSP12.1, SW_M1.1, SW_M2.1, SW_M3.1, SW_M4.1, SW_RGHT1.1, U1.21
reset: J1.5, R6.2, RESET1.2, U1.9
row0: D5.1, D11.1, D17.1, D22.1, D28.1, D34.1, D39.1, D45.1, D50.1, D56.1, D61.1, D67.1, D84.1, U1.35
row1: D0.1, D6.1, D12.1, D18.1, D23.1, D29.1, D35.1, D40.1, D46.1, D51.1, D57.1, D62.1, D68.1, D73.1, D77.1, U1.36
row2: D1.1, D7.1, D13.1, D19.1, D24.1, D30.1, D36.1, D41.1, D47.1, D52.1, D58.1, D63.1, D69.1, D74.1, D78.1, U1.37
row3: D2.1, D8.1, D14.1, D20.1, D25.1, D31.1, D37.1, D42.1, D48.1, D53.1, D59.1, D64.1, D70.1, D79.1, U1.38
row4: D3.1, D9.1, D15.1, D21.1, D26.1, D32.1, D38.1, D43.1, D49.1, D54.1, D60.1, D65.1, D71.1, D75.1, D80.1, U1.39
row5: D4.1, D10.1, D16.1, D27.1, D33.1, D44.1, D55.1, D66.1, D72.1, D76.1, D81.1, U1.40

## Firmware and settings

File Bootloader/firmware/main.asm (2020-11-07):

main.elf:     file format elf32-avr

SYMBOL TABLE:
00007000 l    d  .text	00000000 .text
00800060 l    d  .data	00000000 .data
00800066 l    d  .bss	00000000 .bss
0080009b l    d  .noinit	00000000 .noinit
00000000 l    d  .comment	00000000 .comment
00000000 l    d  .note.gnu.avr.deviceinfo	00000000 .note.gnu.avr.deviceinfo
00000000 l    d  .debug_aranges	00000000 .debug_aranges
00000000 l    d  .debug_info	00000000 .debug_info
00000000 l    d  .debug_abbrev	00000000 .debug_abbrev
00000000 l    d  .debug_line	00000000 .debug_line
00000000 l    d  .debug_frame	00000000 .debug_frame
00000000 l    d  .debug_str	00000000 .debug_str
00000000 l    d  .debug_loc	00000000 .debug_loc
00000000 l    d  .debug_ranges	00000000 .debug_ranges
00000000 l    d  .debug_macro	00000000 .debug_macro
00000000 l    df *ABS*	00000000 main.c
0000003e l       *ABS*	00000000 __SP_H__
0000003d l       *ABS*	00000000 __SP_L__
0000003f l       *ABS*	00000000 __SREG__
00000000 l       *ABS*	00000000 __tmp_reg__
00000001 l       *ABS*	00000000 __zero_reg__
000070e0 l       .text	00000000 __BOOTLOADERENTRY_FROMSOFTWARE__bootup_investigate_RAMEND_done6
000070de l       .text	00000000 __BOOTLOADERENTRY_FROMSOFTWARE__bootup_investigate_RAMEND_mismatch6
0080009c l     O .noinit	00000001 __BOOTLOADERENTRY_FROMSOFTWARE__bootup_RAMEND_doesmatch
0080009b l     O .noinit	00000001 __BOOTLOADERENTRY_FROMSOFTWARE__bootup_MCUCSR
00800062 l     O .data	00000004 signatureBytes
0080006f l     O .bss	00000001 stayinloader
0000741e l       .text	00000000 _mywait_sleeploop227
0000747c l       .text	00000000 _mywait_sleeploop350
00800070 l     O .bss	00000001 usbMsgFlags
00800066 l     O .bss	00000004 replyBuffer.2209
0080006d l     O .bss	00000002 currentAddress
0080006c l     O .bss	00000001 bytesRemaining
0080006b l     O .bss	00000001 isLastPage
0080006a l     O .bss	00000001 currentRequest
00800060 l     O .data	00000001 usbMsgLen
00000000 l    df *ABS*	00000000 _clear_bss.o
00007108 l       .text	00000000 .do_clear_bss_start
00007106 l       .text	00000000 .do_clear_bss_loop
00000000 l    df *ABS*	00000000 usbdrv/usbdrvasm.o
00007138 l       .text	00000000 usbCrcLoopEntry
00007126 l       .text	00000000 usbCrcByteLoop
0000712a l       .text	00000000 usbCrcBitLoop
00007134 l       .text	00000000 usbCrcNoXor
0000713c l       .text	00000000 usbCrcReady
0000714e l       .text	00000000 waitForJ
00007154 l       .text	00000000 waitForK
0000716e l       .text	00000000 foundK
00007280 l       .text	00000000 sofError
00007188 l       .text	00000000 haveTwoBitsK
00007216 l       .text	00000000 rxbit1
000071a4 l       .text	00000000 unstuff6
000071ec l       .text	00000000 didUnstuff6
000071b0 l       .text	00000000 unstuff7
000071fa l       .text	00000000 didUnstuff7
000071bc l       .text	00000000 unstuffEven
0000723a l       .text	00000000 se0
00007212 l       .text	00000000 didUnstuffE
000071cc l       .text	00000000 unstuffOdd
00007226 l       .text	00000000 didUnstuffO
000071dc l       .text	00000000 rxByteLoop
000071e8 l       .text	00000000 skipLeap
00007202 l       .text	00000000 rxBitLoop
00007232 l       .text	00000000 overflow
00007236 l       .text	00000000 ignorePacket
00007268 l       .text	00000000 storeTokenAndReturn
0000728a l       .text	00000000 handleData
000072b4 l       .text	00000000 handleIn
00007268 l       .text	00000000 handleSetupOrOut
0000726c l       .text	00000000 doReturn
000072e8 l       .text	00000000 sendNakAndReti
000072ec l       .text	00000000 sendAckAndReti
000072ee l       .text	00000000 sendCntAndReti
000072f6 l       .text	00000000 usbSendAndReti
000072d0 l       .text	00000000 bitstuffN
00007310 l       .text	00000000 didStuffN
000072dc l       .text	00000000 bitstuff6
0000731e l       .text	00000000 didStuff6
000072e4 l       .text	00000000 bitstuff7
0000732a l       .text	00000000 didStuff7
000072f0 l       .text	00000000 sendX3AndReti
00007304 l       .text	00000000 txByteLoop
00007306 l       .text	00000000 txBitLoop
00007352 l       .text	00000000 skipAddrAssign
00007362 l       .text	00000000 se0Delay
00000000 l    df *ABS*	00000000 _exit.o
00007856 l       .text	00000000 __stop_program
00007084 g     O .text	00000012 usbDescriptorDevice
0000783c g       .text	00000000 eeprom_write_r18
00007146 g     F .text	00000000 __vector_1
00800071 g     O .bss	0000000b usbTxBuf
00000000 g       *ABS*	00000000 nullVector
0000ffa0 g       *ABS*	00000000 __DATA_REGION_LENGTH__
00007072 g       .text	00000000 __trampolines_start
00007858 g       .text	00000000 _etext
000070c0 g     O .text	00000004 usbDescriptorString0
00007112  w      .text	00000000 __vector_12
00007112 g       .text	00000000 __bad_interrupt
0000785e g       *ABS*	00000000 __data_load_end
00007112  w      .text	00000000 __vector_6
00007114 g       .text	00000000 usbCrc16
00007072 g       .text	00000000 __trampolines_end
00007112  w      .text	00000000 __vector_3
000070d0 g     F .text	00000018 __BOOTLOADERENTRY_FROMSOFTWARE__bootup_investigate_RAMEND
00007858 g       *ABS*	00000000 __data_load_start
000070c4 g       .text	00000000 __dtors_end
0080009b g       .bss	00000000 __bss_end
00000400 g       *ABS*	00000000 __LOCK_REGION_LENGTH__
00007054 g     O .text	0000001e bootloader__do_spm
0000783a g     F .text	0000001a eeprom_write_byte
00007112  w      .text	00000000 __vector_11
000070c4  w      .text	00000000 __init
00007112  w      .text	00000000 __vector_13
0000713e g       .text	00000000 usbCrc16Append
00007112  w      .text	00000000 __vector_17
00007112  w      .text	00000000 __vector_19
00007112  w      .text	00000000 __vector_7
00007072 g     O .text	00000012 usbDescriptorConfiguration
000070fe g       .text	00000010 .hidden __do_clear_bss
0080007c g     O .bss	00000001 usbDeviceAddr
00810000 g       .comment	00000000 __eeprom_end
0080007d g     O .bss	00000001 usbRxToken
00007000 g       .text	00000000 __vectors
0000782a g     F .text	00000010 eeprom_read_byte
00800066 g       .data	00000000 __data_end
000070a4 g     O .text	0000001c usbDescriptorStringVendor
0080007e g     O .bss	00000001 usbInputBufOffset
00007000  w      .text	00000000 __vector_default
00007112  w      .text	00000000 __vector_5
00000400 g       *ABS*	00000000 __SIGNATURE_REGION_LENGTH__
000070c4 g       .text	00000000 __ctors_start
000070e8 g       .text	00000016 .hidden __do_copy_data
0000736e g     F .text	0000009e usbFunctionSetup_USBASP_FUNC_TRANSMIT
00800066 g       .bss	00000000 __bss_start
0000740c g     F .text	0000041e main
00007112  w      .text	00000000 __vector_4
00800061 g     O .data	00000001 usbTxLen
00000000  w      *ABS*	00000000 __heap_end
00007112  w      .text	00000000 __vector_9
00007112  w      .text	00000000 __vector_2
00000400 g       *ABS*	00000000 __USER_SIGNATURE_REGION_LENGTH__
0080007f g     O .bss	00000002 usbMsgPtr
00007112  w      .text	00000000 __vector_15
00800081 g     O .bss	00000001 usbRxLen
000070c4 g       .text	00000000 __dtors_start
000070c4 g       .text	00000000 __ctors_end
0000085f  w      *ABS*	00000000 __stack
00800082 g     O .bss	00000001 usbNewDeviceAddr
00800066 g       .data	00000000 _edata
0080009d g       .noinit	00000000 _end
00007112  w      .text	00000000 __vector_8
00007854  w      .text	00000000 .hidden exit
00800083 g     O .bss	00000001 usbCurrentTok
00007096 g     O .text	0000000e usbDescriptorStringDevice
00010000 g       *ABS*	00000000 __EEPROM_REGION_LENGTH__
00007854 g       .text	00000000 .hidden _exit
00800084 g     O .bss	00000001 usbConfiguration
00007112  w      .text	00000000 __vector_14
00007112  w      .text	00000000 __vector_10
00800085 g     O .bss	00000016 usbRxBuf
00007112  w      .text	00000000 __vector_16
00800060 g       .data	00000000 __data_start
00007112  w      .text	00000000 __vector_18
00000400 g       *ABS*	00000000 __FUSE_REGION_LENGTH__
00020000 g       *ABS*	00000000 __TEXT_REGION_LENGTH__
00007112  w      .text	00000000 __vector_20



Disassembly of section .text:

00007000 <__vectors>:
    7000:	61 c0       	rjmp	.+194    	; 0x70c4 <__ctors_end>
    7002:	00 00       	nop
    7004:	a0 c0       	rjmp	.+320    	; 0x7146 <__vector_1>
    7006:	00 00       	nop
    7008:	84 c0       	rjmp	.+264    	; 0x7112 <__bad_interrupt>
    700a:	00 00       	nop
    700c:	82 c0       	rjmp	.+260    	; 0x7112 <__bad_interrupt>
    700e:	00 00       	nop
    7010:	80 c0       	rjmp	.+256    	; 0x7112 <__bad_interrupt>
    7012:	00 00       	nop
    7014:	7e c0       	rjmp	.+252    	; 0x7112 <__bad_interrupt>
    7016:	00 00       	nop
    7018:	7c c0       	rjmp	.+248    	; 0x7112 <__bad_interrupt>
    701a:	00 00       	nop
    701c:	7a c0       	rjmp	.+244    	; 0x7112 <__bad_interrupt>
    701e:	00 00       	nop
    7020:	78 c0       	rjmp	.+240    	; 0x7112 <__bad_interrupt>
    7022:	00 00       	nop
    7024:	76 c0       	rjmp	.+236    	; 0x7112 <__bad_interrupt>
    7026:	00 00       	nop
    7028:	74 c0       	rjmp	.+232    	; 0x7112 <__bad_interrupt>
    702a:	00 00       	nop
    702c:	72 c0       	rjmp	.+228    	; 0x7112 <__bad_interrupt>
    702e:	00 00       	nop
    7030:	70 c0       	rjmp	.+224    	; 0x7112 <__bad_interrupt>
    7032:	00 00       	nop
    7034:	6e c0       	rjmp	.+220    	; 0x7112 <__bad_interrupt>
    7036:	00 00       	nop
    7038:	6c c0       	rjmp	.+216    	; 0x7112 <__bad_interrupt>
    703a:	00 00       	nop
    703c:	6a c0       	rjmp	.+212    	; 0x7112 <__bad_interrupt>
    703e:	00 00       	nop
    7040:	68 c0       	rjmp	.+208    	; 0x7112 <__bad_interrupt>
    7042:	00 00       	nop
    7044:	66 c0       	rjmp	.+204    	; 0x7112 <__bad_interrupt>
    7046:	00 00       	nop
    7048:	64 c0       	rjmp	.+200    	; 0x7112 <__bad_interrupt>
    704a:	00 00       	nop
    704c:	62 c0       	rjmp	.+196    	; 0x7112 <__bad_interrupt>
    704e:	00 00       	nop
    7050:	60 c0       	rjmp	.+192    	; 0x7112 <__bad_interrupt>
	...

00007054 <bootloader__do_spm>:
    7054:	ec 2d fd 2d b7 b6 b0 fc fd cf 27 bf e8 95 b7 b6     .-.-......'.....
    7064:	b0 fc fd cf 21 e1 b7 b6 b6 fc f4 cf 08 95           ....!.........

00007072 <usbDescriptorConfiguration>:
    7072:	09 02 12 00 01 01 00 80 32 09 04 00 00 00 00 00     ........2.......
	...

00007084 <usbDescriptorDevice>:
    7084:	12 01 10 01 ff 00 00 08 c0 16 dc 05 02 01 01 02     ................
    7094:	00 01                                               ..

00007096 <usbDescriptorStringDevice>:
    7096:	0e 03 55 00 53 00 42 00 61 00 73 00 70 00           ..U.S.B.a.s.p.

000070a4 <usbDescriptorStringVendor>:
    70a4:	1c 03 77 00 77 00 77 00 2e 00 66 00 69 00 73 00     ..w.w.w...f.i.s.
    70b4:	63 00 68 00 6c 00 2e 00 64 00 65 00                 c.h.l...d.e.

000070c0 <usbDescriptorString0>:
    70c0:	04 03 09 04                                         ....

000070c4 <__ctors_end>:
    70c4:	11 24       	eor	r1, r1
    70c6:	1f be       	out	0x3f, r1	; 63
    70c8:	cf e5       	ldi	r28, 0x5F	; 95
    70ca:	d8 e0       	ldi	r29, 0x08	; 8
    70cc:	de bf       	out	0x3e, r29	; 62
    70ce:	cd bf       	out	0x3d, r28	; 61

000070d0 <__BOOTLOADERENTRY_FROMSOFTWARE__bootup_investigate_RAMEND>:
/* ------------------------------------------------------------------------ */

#if (HAVE_BOOTLOADERENTRY_FROMSOFTWARE)
void __attribute__ ((section(".init3"),naked,used,no_instrument_function)) __BOOTLOADERENTRY_FROMSOFTWARE__bootup_investigate_RAMEND(void);
void __BOOTLOADERENTRY_FROMSOFTWARE__bootup_investigate_RAMEND(void) {
  asm volatile (
    70d0:	24 b7       	in	r18, 0x34	; 52
    70d2:	d8 e0       	ldi	r29, 0x08	; 8
    70d4:	ce e5       	ldi	r28, 0x5E	; 94
    70d6:	39 91       	ld	r19, Y+
    70d8:	38 33       	cpi	r19, 0x38	; 56
    70da:	39 91       	ld	r19, Y+
    70dc:	09 f0       	breq	.+2      	; 0x70e0 <__BOOTLOADERENTRY_FROMSOFTWARE__bootup_investigate_RAMEND_done6>

000070de <__BOOTLOADERENTRY_FROMSOFTWARE__bootup_investigate_RAMEND_mismatch6>:
    70de:	3f ef       	ldi	r19, 0xFF	; 255

000070e0 <__BOOTLOADERENTRY_FROMSOFTWARE__bootup_investigate_RAMEND_done6>:
    70e0:	30 93 9c 00 	sts	0x009C, r19	; 0x80009c <__BOOTLOADERENTRY_FROMSOFTWARE__bootup_RAMEND_doesmatch>
    70e4:	20 93 9b 00 	sts	0x009B, r18	; 0x80009b <__BOOTLOADERENTRY_FROMSOFTWARE__bootup_MCUCSR>

000070e8 <__do_copy_data>:
    70e8:	10 e0       	ldi	r17, 0x00	; 0
    70ea:	a0 e6       	ldi	r26, 0x60	; 96
    70ec:	b0 e0       	ldi	r27, 0x00	; 0
    70ee:	e8 e5       	ldi	r30, 0x58	; 88
    70f0:	f8 e7       	ldi	r31, 0x78	; 120
    70f2:	02 c0       	rjmp	.+4      	; 0x70f8 <__do_copy_data+0x10>
    70f4:	05 90       	lpm	r0, Z+
    70f6:	0d 92       	st	X+, r0
    70f8:	a6 36       	cpi	r26, 0x66	; 102
    70fa:	b1 07       	cpc	r27, r17
    70fc:	d9 f7       	brne	.-10     	; 0x70f4 <__do_copy_data+0xc>

000070fe <__do_clear_bss>:
    70fe:	20 e0       	ldi	r18, 0x00	; 0
    7100:	a6 e6       	ldi	r26, 0x66	; 102
    7102:	b0 e0       	ldi	r27, 0x00	; 0
    7104:	01 c0       	rjmp	.+2      	; 0x7108 <.do_clear_bss_start>

00007106 <.do_clear_bss_loop>:
    7106:	1d 92       	st	X+, r1

00007108 <.do_clear_bss_start>:
    7108:	ab 39       	cpi	r26, 0x9B	; 155
    710a:	b2 07       	cpc	r27, r18
    710c:	e1 f7       	brne	.-8      	; 0x7106 <.do_clear_bss_loop>
    710e:	7e d1       	rcall	.+764    	; 0x740c <main>
    7110:	a1 c3       	rjmp	.+1858   	; 0x7854 <_exit>

00007112 <__bad_interrupt>:
    7112:	76 cf       	rjmp	.-276    	; 0x7000 <__vectors>

00007114 <usbCrc16>:
;   poly    r20+r21
;   scratch r23
;   resCrc  r24+r25 / r16+r17
;   ptr     X / Z
usbCrc16:
    mov     ptrL, argPtrL
    7114:	a8 2f       	mov	r26, r24
    mov     ptrH, argPtrH
    7116:	b9 2f       	mov	r27, r25
    ldi     resCrcL, 0
    7118:	80 e0       	ldi	r24, 0x00	; 0
    ldi     resCrcH, 0
    711a:	90 e0       	ldi	r25, 0x00	; 0
    ldi     polyL, lo8(0xa001)
    711c:	41 e0       	ldi	r20, 0x01	; 1
    ldi     polyH, hi8(0xa001)
    711e:	50 ea       	ldi	r21, 0xA0	; 160
    com     argLen      ; argLen = -argLen - 1: modified loop to ensure that carry is set
    7120:	60 95       	com	r22
    ldi     bitCnt, 0   ; loop counter with starnd condition = end condition
    7122:	30 e0       	ldi	r19, 0x00	; 0
    rjmp    usbCrcLoopEntry
    7124:	09 c0       	rjmp	.+18     	; 0x7138 <usbCrcLoopEntry>

00007126 <usbCrcByteLoop>:
usbCrcByteLoop:
    ld      byte, ptr+
    7126:	2d 91       	ld	r18, X+
    eor     resCrcL, byte
    7128:	82 27       	eor	r24, r18

0000712a <usbCrcBitLoop>:
usbCrcBitLoop:
    ror     resCrcH     ; carry is always set here (see brcs jumps to here)
    712a:	97 95       	ror	r25
    ror     resCrcL
    712c:	87 95       	ror	r24
    brcs    usbCrcNoXor
    712e:	10 f0       	brcs	.+4      	; 0x7134 <usbCrcNoXor>
    eor     resCrcL, polyL
    7130:	84 27       	eor	r24, r20
    eor     resCrcH, polyH
    7132:	95 27       	eor	r25, r21

00007134 <usbCrcNoXor>:
usbCrcNoXor:
    subi    bitCnt, 224 ; (8 * 224) % 256 = 0; this loop iterates 8 times
    7134:	30 5e       	subi	r19, 0xE0	; 224
    brcs    usbCrcBitLoop
    7136:	c8 f3       	brcs	.-14     	; 0x712a <usbCrcBitLoop>

00007138 <usbCrcLoopEntry>:
usbCrcLoopEntry:
    subi    argLen, -1
    7138:	6f 5f       	subi	r22, 0xFF	; 255
    brcs    usbCrcByteLoop
    713a:	a8 f3       	brcs	.-22     	; 0x7126 <usbCrcByteLoop>

0000713c <usbCrcReady>:
usbCrcReady:
    ret
    713c:	08 95       	ret

0000713e <usbCrc16Append>:

#endif /* USB_USE_FAST_CRC */

; extern unsigned usbCrc16Append(unsigned char *data, unsigned char len);
usbCrc16Append:
    rcall   usbCrc16
    713e:	ea df       	rcall	.-44     	; 0x7114 <usbCrc16>
    st      ptr+, resCrcL
    7140:	8d 93       	st	X+, r24
    st      ptr+, resCrcH
    7142:	9d 93       	st	X+, r25
    ret
    7144:	08 95       	ret

00007146 <__vector_1>:
; Numbers in brackets are clocks counted from center of last sync bit
; when instruction starts

USB_INTR_VECTOR:
;order of registers pushed: YL, SREG YH, [sofError], bitcnt, shift, x1, x2, x3, x4, cnt
    push    YL                  ;[-25] push only what is necessary to sync with edge ASAP
    7146:	cf 93       	push	r28
    in      YL, SREG            ;[-23]
    7148:	cf b7       	in	r28, 0x3f	; 63
    push    YL                  ;[-22]
    714a:	cf 93       	push	r28
    push    YH                  ;[-20]
    714c:	df 93       	push	r29

0000714e <waitForJ>:
;sync up with J to K edge during sync pattern -- use fastest possible loops
;The first part waits at most 1 bit long since we must be in sync pattern.
;YL is guarenteed to be < 0x80 because I flag is clear. When we jump to
;waitForJ, ensure that this prerequisite is met.
waitForJ:
    inc     YL
    714e:	c3 95       	inc	r28
    sbis    USBIN, USBMINUS
    7150:	83 9b       	sbis	0x10, 3	; 16
    brne    waitForJ        ; just make sure we have ANY timeout
    7152:	e9 f7       	brne	.-6      	; 0x714e <waitForJ>

00007154 <waitForK>:
waitForK:
;The following code results in a sampling window of < 1/4 bit which meets the spec.
    sbis    USBIN, USBMINUS     ;[-15]
    7154:	83 9b       	sbis	0x10, 3	; 16
    rjmp    foundK              ;[-14]
    7156:	0b c0       	rjmp	.+22     	; 0x716e <foundK>
    sbis    USBIN, USBMINUS
    7158:	83 9b       	sbis	0x10, 3	; 16
    rjmp    foundK
    715a:	09 c0       	rjmp	.+18     	; 0x716e <foundK>
    sbis    USBIN, USBMINUS
    715c:	83 9b       	sbis	0x10, 3	; 16
    rjmp    foundK
    715e:	07 c0       	rjmp	.+14     	; 0x716e <foundK>
    sbis    USBIN, USBMINUS
    7160:	83 9b       	sbis	0x10, 3	; 16
    rjmp    foundK
    7162:	05 c0       	rjmp	.+10     	; 0x716e <foundK>
    sbis    USBIN, USBMINUS
    7164:	83 9b       	sbis	0x10, 3	; 16
    rjmp    foundK
    7166:	03 c0       	rjmp	.+6      	; 0x716e <foundK>
    sbis    USBIN, USBMINUS
    7168:	83 9b       	sbis	0x10, 3	; 16
    rjmp    foundK
    716a:	01 c0       	rjmp	.+2      	; 0x716e <foundK>
    sts     usbSofCount, YL
#endif  /* USB_COUNT_SOF */
#ifdef USB_SOF_HOOK
    USB_SOF_HOOK
#endif
    rjmp    sofError
    716c:	89 c0       	rjmp	.+274    	; 0x7280 <sofError>

0000716e <foundK>:
foundK:                         ;[-12]
;{3, 5} after falling D- edge, average delay: 4 cycles [we want 5 for center sampling]
;we have 1 bit time for setup purposes, then sample again. Numbers in brackets
;are cycles from center of first sync (double K) bit after the instruction
    push    bitcnt              ;[-12]
    716e:	6f 93       	push	r22
;   [---]                       ;[-11]
    lds     YL, usbInputBufOffset;[-10]
    7170:	c0 91 7e 00 	lds	r28, 0x007E	; 0x80007e <usbInputBufOffset>
;   [---]                       ;[-9]
    clr     YH                  ;[-8]
    7174:	dd 27       	eor	r29, r29
    subi    YL, lo8(-(usbRxBuf));[-7] [rx loop init]
    7176:	cb 57       	subi	r28, 0x7B	; 123
    sbci    YH, hi8(-(usbRxBuf));[-6] [rx loop init]
    7178:	df 4f       	sbci	r29, 0xFF	; 255
    push    shift               ;[-5]
    717a:	2f 93       	push	r18
;   [---]                       ;[-4]
    ldi     bitcnt, 0x55        ;[-3] [rx loop init]
    717c:	65 e5       	ldi	r22, 0x55	; 85
    sbis    USBIN, USBMINUS     ;[-2] we want two bits K (sample 2 cycles too early)
    717e:	83 9b       	sbis	0x10, 3	; 16
    rjmp    haveTwoBitsK        ;[-1]
    7180:	03 c0       	rjmp	.+6      	; 0x7188 <haveTwoBitsK>
    pop     shift               ;[0] undo the push from before
    7182:	2f 91       	pop	r18
    pop     bitcnt              ;[2] undo the push from before
    7184:	6f 91       	pop	r22
    rjmp    waitForK            ;[4] this was not the end of sync, retry
    7186:	e6 cf       	rjmp	.-52     	; 0x7154 <waitForK>

00007188 <haveTwoBitsK>:

;----------------------------------------------------------------------------
; push more registers and initialize values while we sample the first bits:
;----------------------------------------------------------------------------
haveTwoBitsK:
    push    x1              ;[1]
    7188:	0f 93       	push	r16
    push    x2              ;[3]
    718a:	1f 93       	push	r17
    push    x3              ;[5]
    718c:	4f 93       	push	r20
    ldi     shift, 0        ;[7]
    718e:	20 e0       	ldi	r18, 0x00	; 0
    ldi     x3, 1<<4        ;[8] [rx loop init] first sample is inverse bit, compensate that
    7190:	40 e1       	ldi	r20, 0x10	; 16
    push    x4              ;[9] == leap
    7192:	5f 93       	push	r21

    in      x1, USBIN       ;[11] <-- sample bit 0
    7194:	00 b3       	in	r16, 0x10	; 16
    andi    x1, USBMASK     ;[12]
    7196:	0c 70       	andi	r16, 0x0C	; 12
    bst     x1, USBMINUS    ;[13]
    7198:	03 fb       	bst	r16, 3
    bld     shift, 7        ;[14]
    719a:	27 f9       	bld	r18, 7
    push    cnt             ;[15]
    719c:	3f 93       	push	r19
    ldi     leap, 0         ;[17] [rx loop init]
    719e:	50 e0       	ldi	r21, 0x00	; 0
    ldi     cnt, USB_BUFSIZE;[18] [rx loop init]
    71a0:	3b e0       	ldi	r19, 0x0B	; 11
    rjmp    rxbit1          ;[19] arrives at [21]
    71a2:	39 c0       	rjmp	.+114    	; 0x7216 <rxbit1>

000071a4 <unstuff6>:

; duration of unstuffing code should be 10.66666667 cycles. We adjust "leap"
; accordingly to approximate this value in the long run.

unstuff6:
    andi    x2, USBMASK ;[03]
    71a4:	1c 70       	andi	r17, 0x0C	; 12
    ori     x3, 1<<6    ;[04] will not be shifted any more
    71a6:	40 64       	ori	r20, 0x40	; 64
    andi    shift, ~0x80;[05]
    71a8:	2f 77       	andi	r18, 0x7F	; 127
    mov     x1, x2      ;[06] sampled bit 7 is actually re-sampled bit 6
    71aa:	01 2f       	mov	r16, r17
    subi    leap, -1    ;[07] total duration = 11 bits -> subtract 1/3
    71ac:	5f 5f       	subi	r21, 0xFF	; 255
    rjmp    didUnstuff6 ;[08]
    71ae:	1e c0       	rjmp	.+60     	; 0x71ec <didUnstuff6>

000071b0 <unstuff7>:
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

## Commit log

2020-07-14 Plate files
    An attempt at making an FR4 plate in KiCad.
    [5db4cd1023def308aeaad9d0dd17626f76137ae5_switch.dxf, Bonsai Plate.kicad_pcb, Bonsai Plate.sch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]
2020-07-14 Fixed missing VCC trace
    [Bonsai.kicad_pcb]
2020-07-15 Fixed a missing trace.
    [Bonsai.kicad_pcb]
2020-07-15 Fixed some via too close errors
    [Bonsai.kicad_pcb]
2020-07-16 Working on the plate and potentially a stacked acrylic case.
2020-07-19 Leveled out the bottom of the pcb.
    [Bonsai.kicad_pcb]
2020-07-19 Fixed the plate to match the pcb adjustment and cleaned up some of the double lines.
    [Bonsai Plate.kicad_pcb]
2020-07-21 Cleared some space around the backspace stab holes.
    [Bonsai.kicad_pcb]
2020-07-26 Fixed plate, added art to the PCB and made a base plate with art.
    [Bonsai Base Plate.kicad_pcb, Bonsai Base Plate.sch, Bonsai Plate.kicad_pcb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]
2020-07-26 Generated gerbers.
    [Bonsai Base Plate-B_Cu.gbl, Bonsai Base Plate-B_Mask.gbs, Bonsai Base Plate-B_SilkS.gbo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]
2020-07-30 Removed the hole labels from the silk screen.
    [5db4cd1023def308aeaad9d0dd17626f76137ae5_switch.dxf, Bonsai Base Plate.kicad_pcb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]
2020-09-20 Cleaned up folders and files
    [5db4cd1023def308aeaad9d0dd17626f76137ae5_switch.dxf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]
2020-10-12 Cleaned up a little and added a case
2020-10-12 Added README.md to the Case folder
2020-11-07 Updated the case Readme and added some pictures.
2020-11-22 Added a guide for assembly
    I've added a guide for either the FR4 style board or the Acrylic style board.
2020-11-22 Added pictures of the acrylic case to the homepage.
